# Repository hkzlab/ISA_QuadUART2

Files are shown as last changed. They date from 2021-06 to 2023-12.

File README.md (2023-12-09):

# ISA Quad UART Adapter (2 + 2)

## Introduction

This 8-bit ISA board will provide 4 serial RS232 ports using a single 16C554 controller.

Port 1 and 2 are exposed on the bracked as DB9 male connectors. Port 3 and 4 are internal.

IRQs will be shared between port 1/3 and port 2/4.

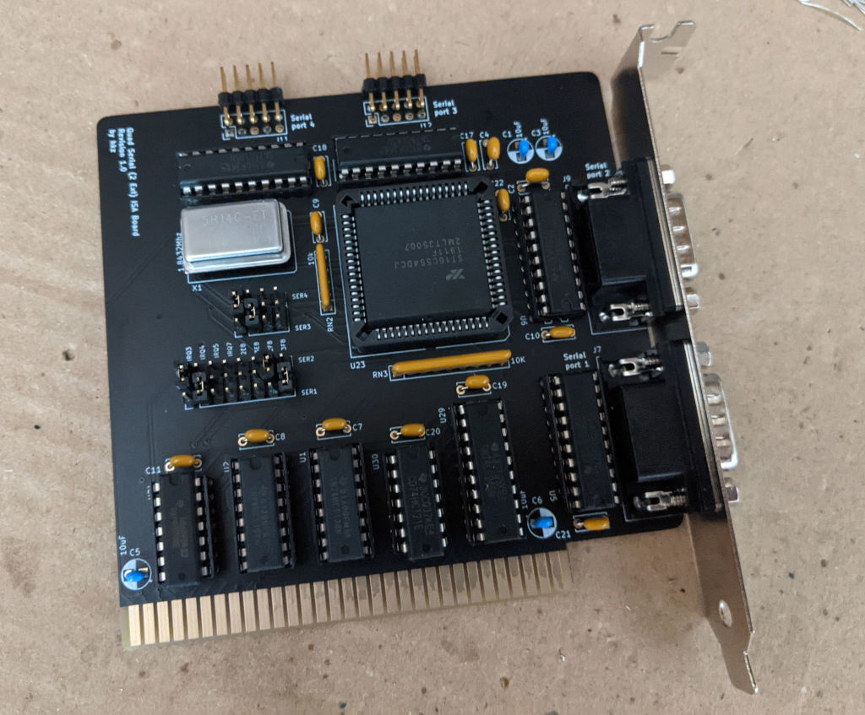
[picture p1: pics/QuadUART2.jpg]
ISA QuadUART 2


### Disclaimer

I take NO responsibility for what happens if you decide to build and use this card. Your computer might crash, catch fire or be destroyed in other nasty ways.
You're encourauged to take what you deem fit from this, and use it in your projects!

## Configuration

This board is configured via two blocks of jumpers:

```text
    .... SER4 
    ....
    .... SER3
IIII2323
RRRREEFF
QQQQ8888
3457
........ SER2
........
........ SER1
```

The upper block will select the address for port 3 (first row) and port 4 (third row). To select an address, you need to bridge the middle row at the specified address with the top or bottom row (depending on which port you wish to assign that address).

The bottom block selects the address for ports 1 and 2, and the IRQs for ports 1/3 and 2/4. The principle is the same.

Default configuration is as follow:
```text
    |... SER4 
    ||..
    .|.. SER3
IIII2323
RRRREEFF
QQQQ8888
3457
|.....|. SER2
||....||
.|.....| SER1
```

Which will assign 0x3F8 to port 1, 0x2F8 to port 2, 0x3E8 to port 3 and 0x2E8 to port 4.
Port 1/3 will get IRQ4 and port 2/4 will get IRQ3.

## Bill of Materials

- 4x 10uF / 25v capacitors
- 13x 100nF / 25v ceramic capacitors
- 1x 9-pin 10k bussed resistor network (RN3)
- 1x 5-pin 10k bussed resistor network (RN2)
- 1x 1.8432Mhz DIP14 or DIP8 oscillator
- 2x DB9 right angle, male, PCB mount connector
- 1x 1x20pin 2.54mm straight header strip (you will cut this as needed)
- 1x 2x20pin 2.54mm straight header strip (you will cut this as needed)
- 1x 2x20pin 2.54mm angled header strip (you will cut this as needed)
- 4x 75C185 RS232 drivers (U5, U6, U25, U26)
- 2x 74HCT138 (U1, U2)
- 1x 74HCT32 (U24)
- 1x 74HCT21 (U30)
- 1x 74HCT245 (U29) (with some controllers, like TL16C554, I noticed improved stability by using a 74LS245)
- 1x SC16C654, ST16C554 (U23) (all the 16C554 / 16C654 should be compatible, but to get TL16C554 working properly I had to replace U29) 
- Jumpers for board configuration
- Keystone 9200-15 bracket
- 1x PLCC68 THT socket
 
## Credits

- Thanks to [@A-Small-Mice](https://github.com/A-Small-Mice) for the printable bracket

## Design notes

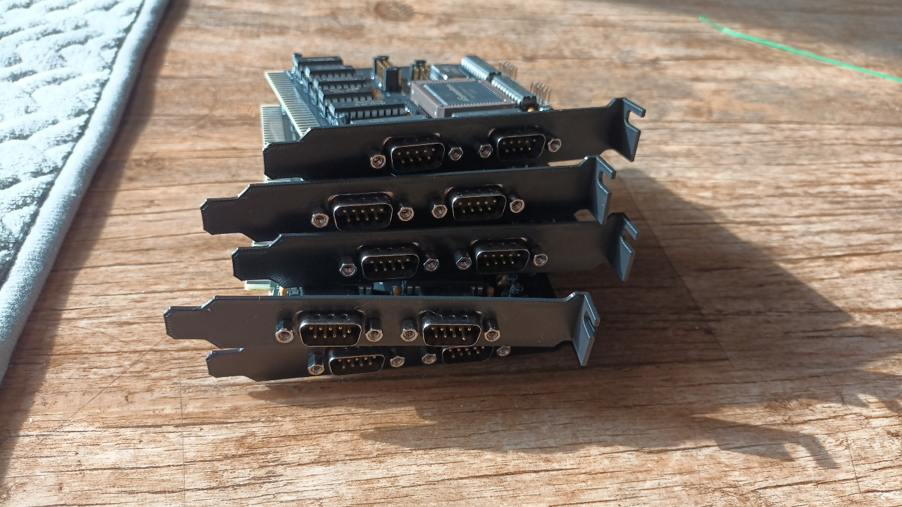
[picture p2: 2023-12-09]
3d_model/3dmodel.jpg

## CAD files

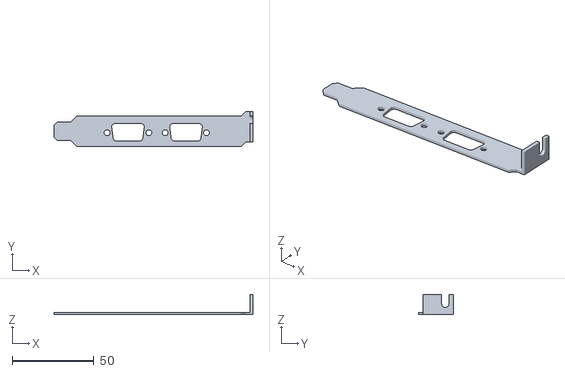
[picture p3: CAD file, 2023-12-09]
3d_model/ISA_QuadUART2_bracket.stl
121.7 x 21.4 x 12.4

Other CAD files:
3d_model/ISA_QuadUART2_bracket.f3d

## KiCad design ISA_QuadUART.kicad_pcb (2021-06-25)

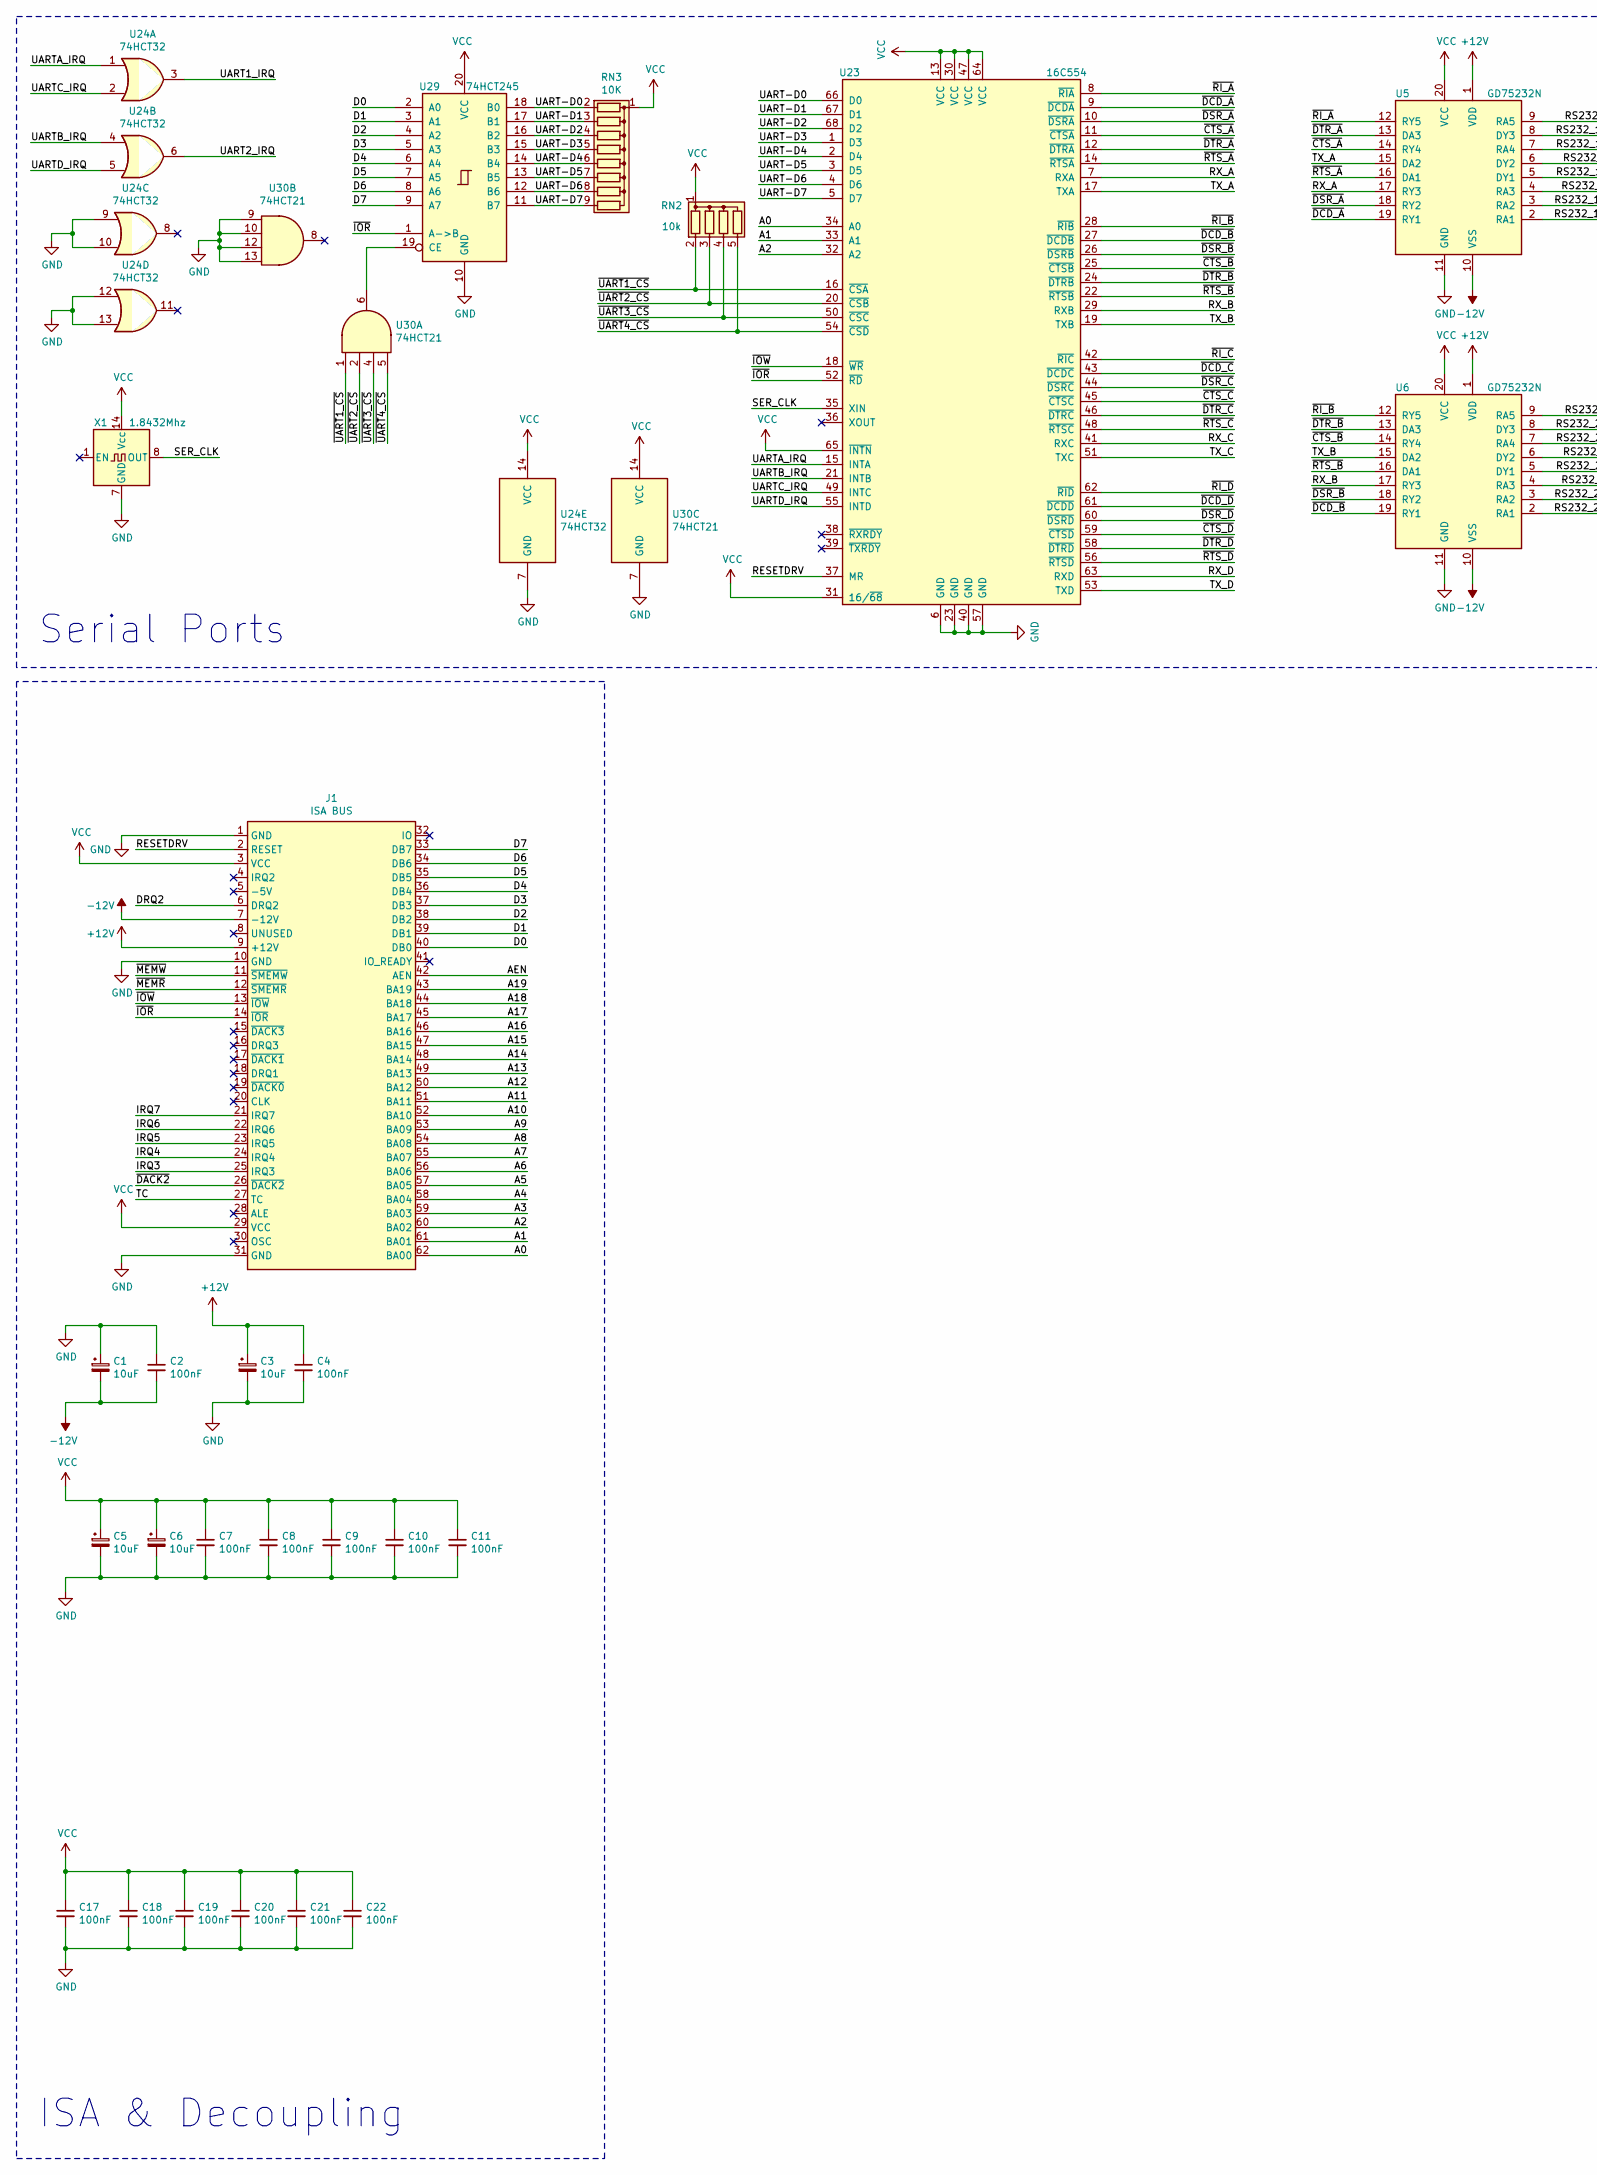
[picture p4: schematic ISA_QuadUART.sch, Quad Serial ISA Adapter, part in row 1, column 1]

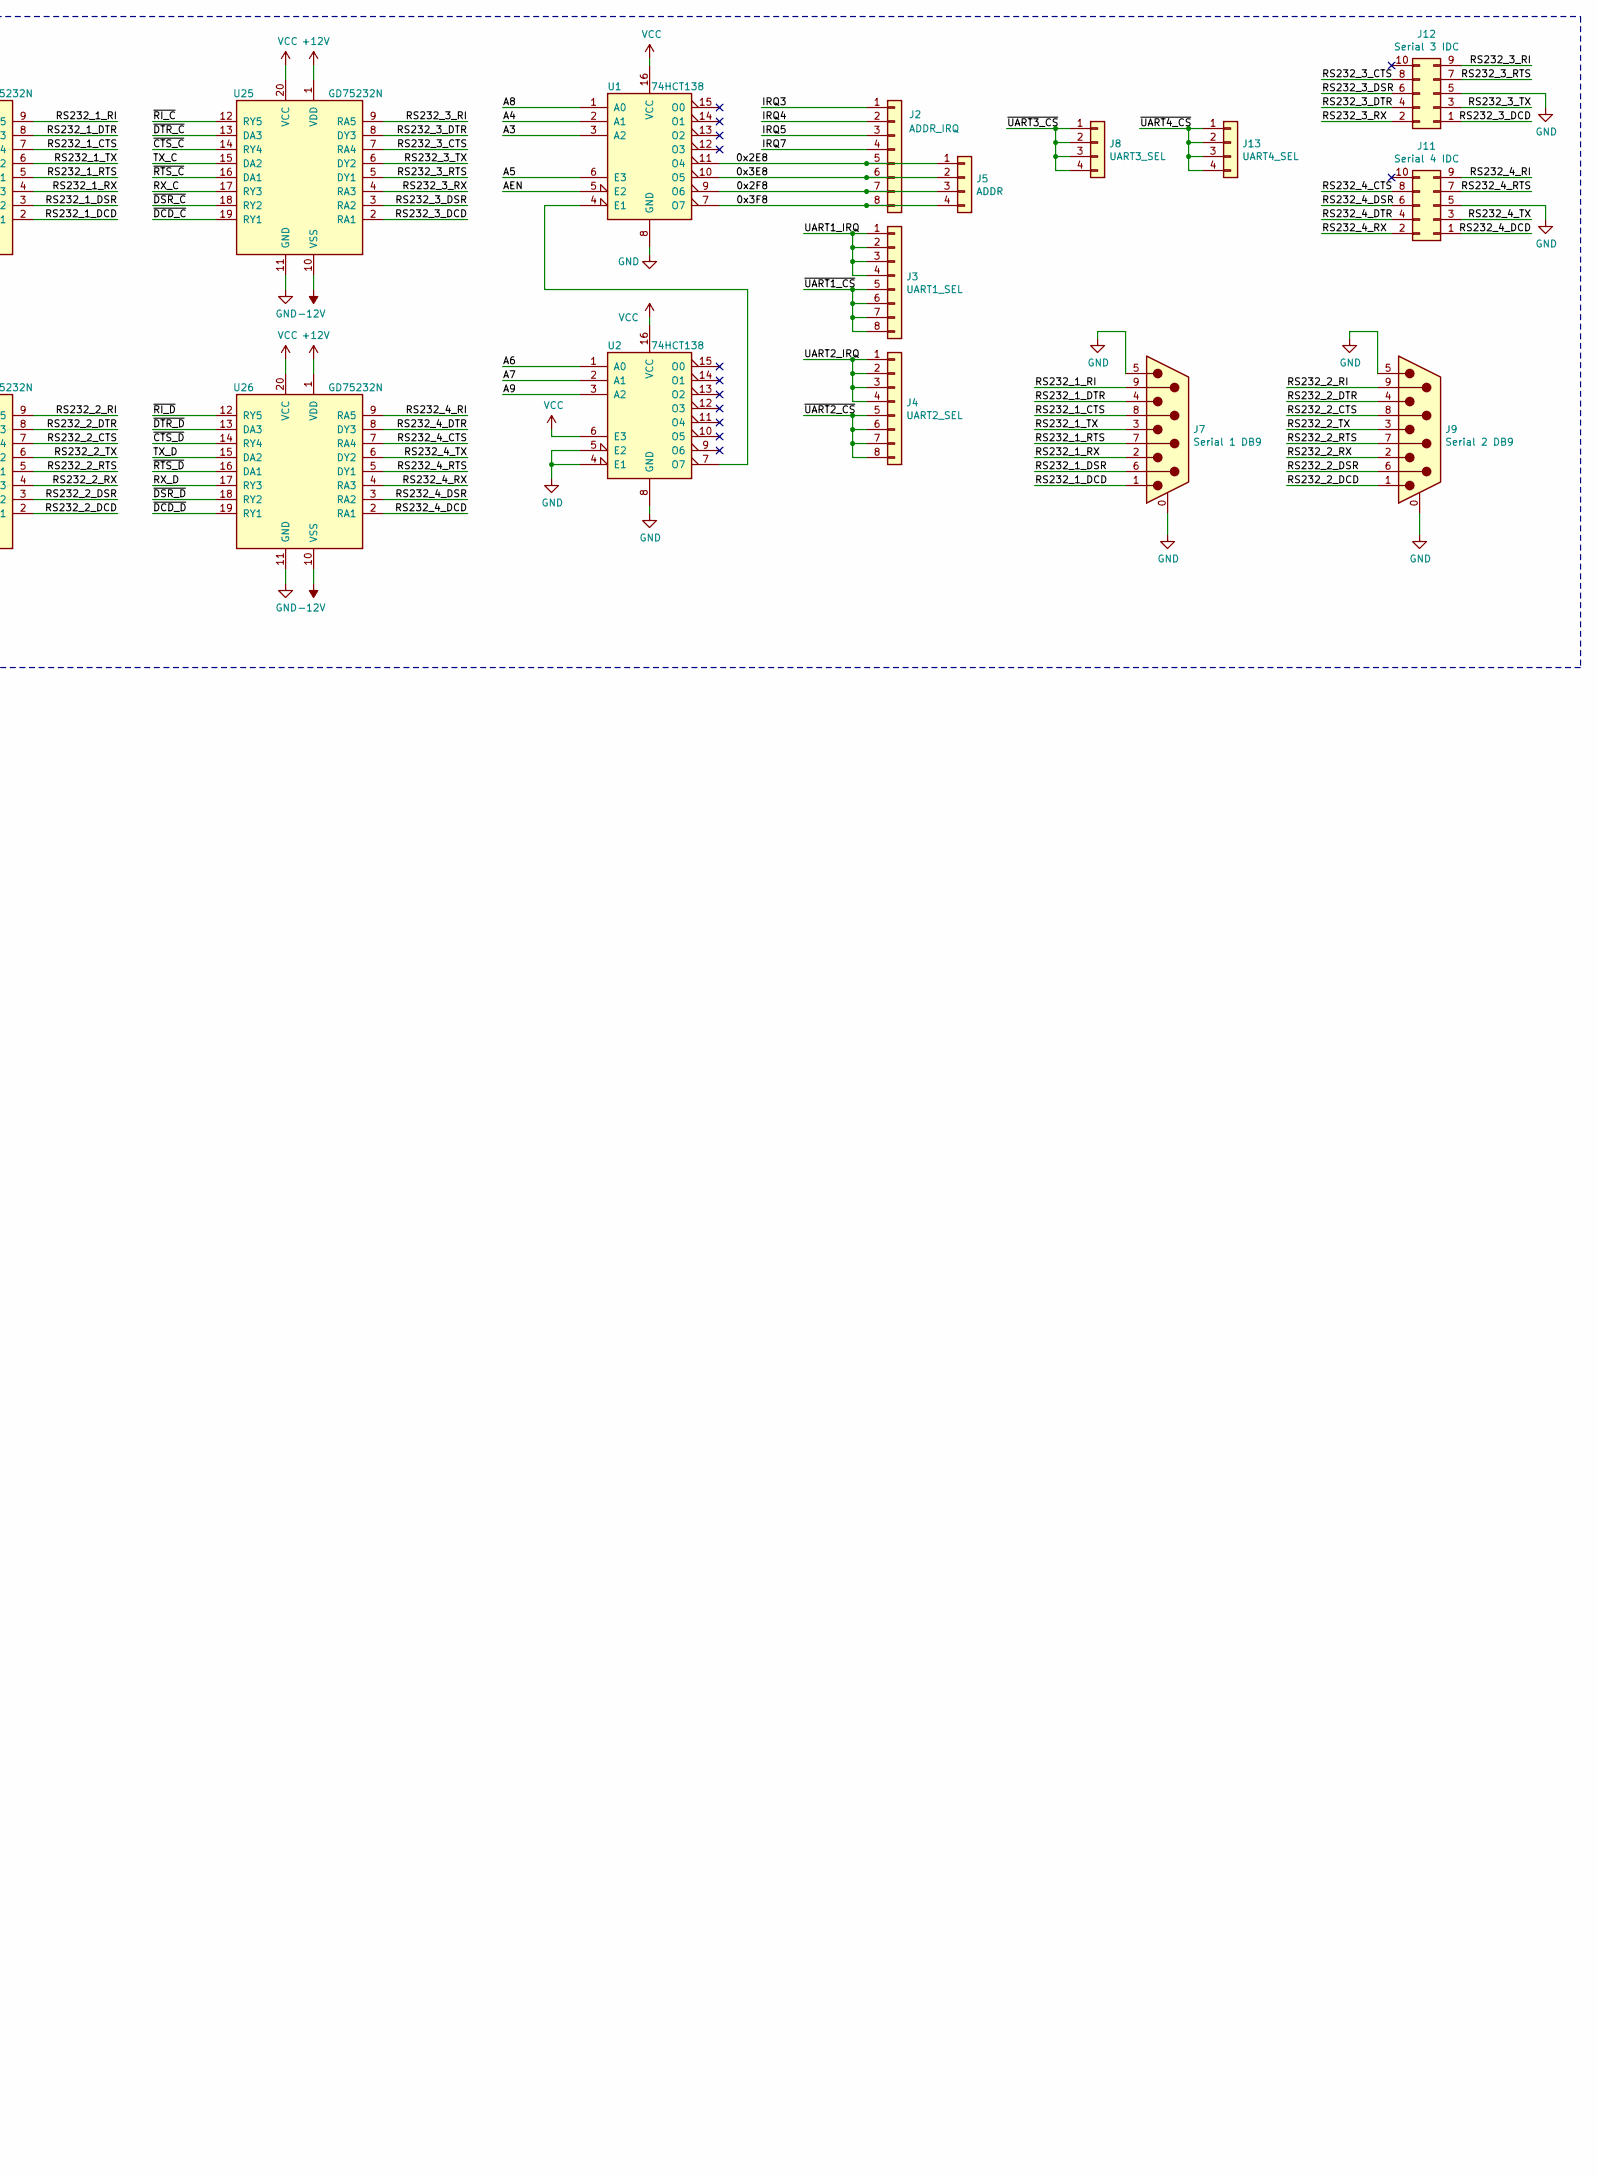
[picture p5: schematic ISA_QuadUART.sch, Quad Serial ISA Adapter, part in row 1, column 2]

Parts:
C1, C3, C5, C6: 10uF; CP_Radial_D5.0mm_P2.50mm
C2, C4, C7, C8, C9, C10, C11, C17, C18, C19, C20, C21, C22: 100nF; C_Disc_D6.0mm_W2.5mm_P5.00mm
J1: ISA BUS; Conn_Edge_PCB_ISA8
J2: ADDR_IRQ; PinHeader_1x08_P2.54mm_Vertical
J3: UART1_SEL; PinHeader_1x08_P2.54mm_Vertical
J4: UART2_SEL; PinHeader_1x08_P2.54mm_Vertical
J5: ADDR; PinHeader_1x04_P2.54mm_Vertical
J7: Serial 1 DB9; DSUB-9_Male_Horizontal_P2.77x2.84mm_EdgePinOffset7.70mm_Hou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
J8: UART3_SEL; PinHeader_1x04_P2.54mm_Vertical
J9: Serial 2 DB9; DSUB-9_Male_Horizontal_P2.77x2.84mm_EdgePinOffset7.70mm_Hou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
J11: Serial 4 IDC; PinHeader_2x05_P2.54mm_Vertical
J12: Serial 3 IDC; PinHeader_2x05_P2.54mm_Vertical
J13: UART4_SEL; PinHeader_1x04_P2.54mm_Vertical
RN2: 10k; R_Array_SIP5
RN3: 10K; R_Array_SIP9
U1, U2: 74HCT138; DIP-16_W7.62mm_LongPads
U5, U6, U25, U26: GD75232N; DIP-20_W7.62mm_LongPads
U23: 16C554; PLCC-68_THT-Socket
U24: 74HCT32; DIP-14_W7.62mm_LongPads
U29: 74HCT245; DIP-20_W7.62mm_LongPads
U30: 74HCT21; DIP-14_W7.62mm_LongPads
X1: 1.8432Mhz; Oscillator_DIP-14-8

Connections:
+12V: C3.1, C4.1, J1.9 (+12V), U5.1 (VDD), U6.1 (VDD), U25.1 (VDD), U26.1 (VDD)
-12V: C1.2, C2.2, J1.7 (-12V), U5.10 (VSS), U6.10 (VSS), U25.10 (VSS), U26.10 (VSS)
/0x2E8: J2.5, J5.1, U1.11 (O4)
/0x2F8: J2.7, J5.3, U1.9 (O6)
/0x3E8: J2.6, J5.2, U1.10 (O5)
/0x3F8: J2.8, J5.4, U1.7 (O7)
/A0: J1.62 (BA00), U23.34 (A0)
/A1: J1.61 (BA01), U23.33 (A1)
/A2: J1.60 (BA02), U23.32 (A2)
/A3: J1.59 (BA03), U1.3 (A2)
/A4: J1.58 (BA04), U1.2 (A1)
/A5: J1.57 (BA05), U1.6 (E3)
/A6: J1.56 (BA06), U2.1 (A0)
/A7: J1.55 (BA07), U2.2 (A1)
/A8: J1.54 (BA08), U1.1 (A0)
/A9: J1.53 (BA09), U2.3 (A2)
/A10: J1.52 (BA10)
/A11: J1.51 (BA11)
/A12: J1.50 (BA12)
/A13: J1.49 (BA13)
/A14: J1.48 (BA14)
/A15: J1.47 (BA15)
/A16: J1.46 (BA16)
/A17: J1.45 (BA17)
/A18: J1.44 (BA18)
/A19: J1.43 (BA19)
/AEN: J1.42 (AEN), U1.5 (E2)
/D0: J1.40 (DB0), U29.2 (A0)
/D1: J1.39 (DB1), U29.3 (A1)
/D2: J1.38 (DB2), U29.4 (A2)
/D3: J1.37 (DB3), U29.5 (A3)
/D4: J1.36 (DB4), U29.6 (A4)
/D5: J1.35 (DB5), U29.7 (A5)
/D6: J1.34 (DB6), U29.8 (A6)
/D7: J1.33 (DB7), U29.9 (A7)
/DRQ2: J1.6 (DRQ2)
/IRQ3: J1.25 (IRQ3), J2.1
/IRQ4: J1.24 (IRQ4), J2.2
/IRQ5: J1.23 (IRQ5), J2.3
/IRQ6: J1.22 (IRQ6)
/IRQ7: J1.21 (IRQ7), J2.4
/RESETDRV: J1.2 (RESET), U23.37 (MR)
/RS232_1_CTS: J7.8, U5.7 (RA4)
/RS232_1_DCD: J7.1, U5.2 (RA1)
/RS232_1_DSR: J7.6, U5.3 (RA2)
/RS232_1_DTR: J7.4, U5.8 (DY3)
/RS232_1_RI: J7.9, U5.9 (RA5)
/RS232_1_RTS: J7.7, U5.5 (DY1)
/RS232_1_RX: J7.2, U5.4 (RA3)
/RS232_1_TX: J7.3, U5.6 (DY2)
/RS232_2_CTS: J9.8, U6.7 (RA4)
/RS232_2_DCD: J9.1, U6.2 (RA1)
/RS232_2_DSR: J9.6, U6.3 (RA2)
/RS232_2_DTR: J9.4, U6.8 (DY3)
/RS232_2_RI: J9.9, U6.9 (RA5)
/RS232_2_RTS: J9.7, U6.5 (DY1)
/RS232_2_RX: J9.2, U6.4 (RA3)
/RS232_2_TX: J9.3, U6.6 (DY2)
/RS232_3_CTS: J12.8, U25.7 (RA4)
/RS232_3_DCD: J12.1, U25.2 (RA1)
/RS232_3_DSR: J12.6, U25.3 (RA2)
/RS232_3_DTR: J12.4, U25.8 (DY3)
/RS232_3_RI: J12.9, U25.9 (RA5)
/RS232_3_RTS: J12.7, U25.5 (DY1)
/RS232_3_RX: J12.2, U25.4 (RA3)
/RS232_3_TX: J12.3, U25.6 (DY2)
/RS232_4_CTS: J11.8, U26.7 (RA4)
/RS232_4_DCD: J11.1, U26.2 (RA1)
/RS232_4_DSR: J11.6, U26.3 (RA2)
/RS232_4_DTR: J11.4, U26.8 (DY3)
/RS232_4_RI: J11.9, U26.9 (RA5)
/RS232_4_RTS: J11.7, U26.5 (DY1)
/RS232_4_RX: J11.2, U26.4 (RA3)
/RS232_4_TX: J11.3, U26.6 (DY2)
/RX_A: U5.17 (RY3), U23.7 (RXA)
/RX_B: U6.17 (RY3), U23.29 (RXB)
/RX_C: U23.41 (RXC), U25.17 (RY3)
/RX_D: U23.63 (RXD), U26.17 (RY3)
/SER_CLK: U23.35 (XIN), X1.8 (OUT)
/TC: J1.27 (TC)
/TX_A: U5.15 (DA2), U23.17 (TXA)
/TX_B: U6.15 (DA2), U23.19 (TXB)
/TX_C: U23.51 (TXC), U25.15 (DA2)
/TX_D: U23.53 (TXD), U26.15 (DA2)
/UART1_IRQ: J3.1, J3.2, J3.3, J3.4, U24.3
/UART2_IRQ: J4.1, J4.2, J4.3, J4.4, U24.6
/UART-D0: RN3.2 (R1), U23.66 (D0), U29.18 (B0)
/UART-D1: RN3.3 (R2), U23.67 (D1), U29.17 (B1)
/UART-D2: RN3.4 (R3), U23.68 (D2), U29.16 (B2)
/UART-D3: RN3.5 (R4), U23.1 (D3), U29.15 (B3)
/UART-D4: RN3.6 (R5), U23.2 (D4), U29.14 (B4)
/UART-D5: RN3.7 (R6), U23.3 (D5), U29.13 (B5)
/UART-D6: RN3.8 (R7), U23.4 (D6), U29.12 (B6)
/UART-D7: RN3.9 (R8), U23.5 (D7), U29.11 (B7)
/UARTA_IRQ: U23.15 (INTA), U24.1
/UARTB_IRQ: U23.21 (INTB), U24.4
/UARTC_IRQ: U23.49 (INTC), U24.2
/UARTD_IRQ: U23.55 (INTD), U24.5
/~CTS_A: U5.14 (RY4), U23.11 (~CTSA)
/~CTS_B: U6.14 (RY4), U23.25 (~CTSB)
/~CTS_C: U23.45 (~CTSC), U25.14 (RY4)
/~CTS_D: U23.59 (~CTSD), U26.14 (RY4)
/~DACK2: J1.26 (~DACK2)
/~DCD_A: U5.19 (RY1), U23.9 (~DCDA)
/~DCD_B: U6.19 (RY1), U23.27 (~DCDB)
/~DCD_C: U23.43 (~DCDC), U25.19 (RY1)
/~DCD_D: U23.61 (~DCDD), U26.19 (RY1)
/~DSR_A: U5.18 (RY2), U23.10 (~DSRA)
/~DSR_B: U6.18 (RY2), U23.26 (~DSRB)
/~DSR_C: U23.44 (~DSRC), U25.18 (RY2)
/~DSR_D: U23.60 (~DSRD), U26.18 (RY2)
/~DTR_A: U5.13 (DA3), U23.12 (~DTRA)
/~DTR_B: U6.13 (DA3), U23.24 (~DTRB)
/~DTR_C: U23.46 (~DTRC), U25.13 (DA3)
/~DTR_D: U23.58 (~DTRD), U26.13 (DA3)
/~IOR: J1.14 (~IOR), U23.52 (~RD~), U29.1 (A->B)
/~IOW: J1.13 (~IOW), U23.18 (~WR~)
/~MEMR: J1.12 (~SMEMR)
/~MEMW: J1.11 (~SMEMW)
/~RI_A: U5.12 (RY5), U23.8 (~RIA)
/~RI_B: U6.12 (RY5), U23.28 (~RIB)
/~RI_C: U23.42 (~RIC), U25.12 (RY5)
/~RI_D: U23.62 (~RID), U26.12 (RY5)
/~RTS_A: U5.16 (DA1), U23.14 (~RTSA)
/~RTS_B: U6.16 (DA1), U23.22 (~RTSB)
/~RTS_C: U23.48 (~RTSC), U25.16 (DA1)
/~RTS_D: U23.56 (~RTSD), U26.16 (DA1)
/~UART1_CS: J3.5, J3.6, J3.7, J3.8, RN2.2 (R1), U23.16 (~CSA), U30.1
/~UART2_CS: J4.5, J4.6, J4.7, J4.8, RN2.3 (R2), U23.20 (~CSB), U30.2
/~UART3_CS: J8.1, J8.2, J8.3, J8.4, RN2.4 (R3), U23.50 (~CSC), U30.4
/~UART4_CS: J13.1, J13.2, J13.3, J13.4, RN2.5 (R4), U23.54 (~CSD), U30.5
GND: C1.1, C2.1, C3.2, C4.2, C5.2, C6.2, C7.2, C8.2, C9.2, C10.2, C11.2, C17.2, C18.2, C19.2, C20.2, C21.2, C22.2, J1.1 (GND), J1.10 (GND), J1.31 (GND), J7.0 (PAD), J7.5, J9.0 (PAD), J9.5, J11.5, J12.5, U1.8 (GND), U2.4 (E1), U2.5 (E2), U2.8 (GND), U5.11 (GND), U6.11 (GND), U23.6 (GND), U23.23 (GND), U23.40 (GND), U23.57 (GND), U24.7 (GND), U24.9, U24.10, U24.12, U24.13, U25.11 (GND), U26.11 (GND), U29.10 (GND), U30.7 (GND), U30.9, U30.10, U30.12, U30.13, X1.7 (GND)
unnamed: U1.4 (E1), U2.7 (O7)
unnamed: U29.19 (CE), U30.6
VCC: C5.1, C6.1, C7.1, C8.1, C9.1, C10.1, C11.1, C17.1, C18.1, C19.1, C20.1, C21.1, C22.1, J1.3 (VCC), J1.29 (VCC), RN2.1 (common), RN3.1 (common), U1.16 (VCC), U2.6 (E3), U2.16 (VCC), U5.20 (VCC), U6.20 (VCC), U23.13 (VCC), U23.30 (VCC), U23.31 (16/~68), U23.47 (VCC), U23.64 (VCC), U23.65 (~INTN), U24.14 (VCC), U25.20 (VCC), U26.20 (VCC), U29.20 (VCC), U30.14 (VCC), X1.14 (Vcc)

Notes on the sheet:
Serial Ports
ISA & Decoupling

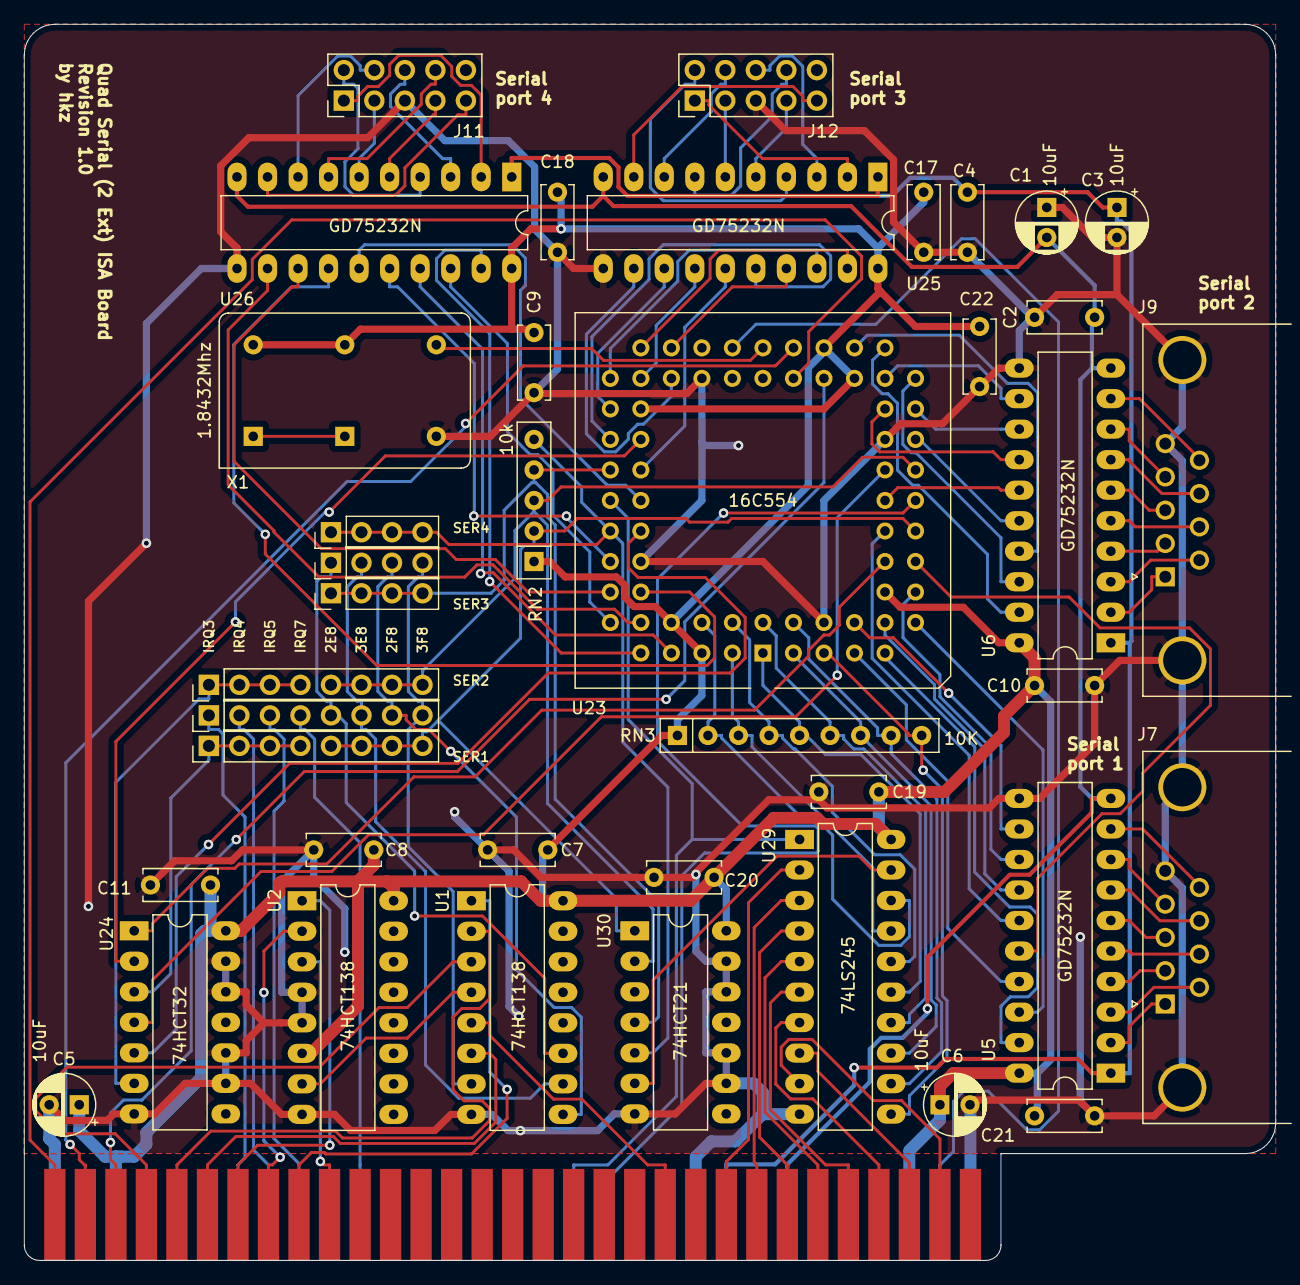
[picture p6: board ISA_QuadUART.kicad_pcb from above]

Board: 2 copper layers, 104.1 x 102.9 mm, 41 parts (0 on the bottom side), 119 nets.

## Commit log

2021-02-20 Import older project
    [ISA_SerPaROM.kicad_pcb, ISA_SerPaROM.sch]
2021-02-20 Additional parallel ports
    [ISA_SerPaROM.sch]
2021-02-20 Route Serial/Parallel/ROM board
    [ISA_SerPaROM.kicad_pcb, ISA_SerPaROM.sch]
2021-02-20 Fix silkscreen
    [ISA_SerPaROM.kicad_pcb]
2021-02-20 Add rev 1.0 gerbers
2021-02-20 Save gerber path
    [ISA_SerPaROM.kicad_pcb]
2021-02-22 Add notes to the schematic, cleaned the silkscreen
    [ISA_SerPaROM.kicad_pcb, ISA_SerPaROM.sch]
2021-02-23 Update mask and gerbers
    [ISA_SerPaROM.kicad_pcb]
2021-03-17 Update silkscreen
    [ISA_SerPaROM.kicad_pcb, ISA_SerPaROM.sch]
2021-03-18 set resistor type for '554 pullup to 4.7k
    [ISA_SerPaROM.kicad_pcb]
2021-03-18 Added LED bar and moved serial leds
    [ISA_SerPaROM.kicad_pcb, ISA_SerPaROM.sch]
2021-03-18 Mark pin 36 as unconnected
    [ISA_SerPaROM.sch]
2021-03-19 Mark some active low signals as such in parport
    [ISA_SerPaROM.sch]
2021-03-19 Remove ROM, add buffer for uart
    [ISA_SerPaROM.kicad_pcb, ISA_SerPaROM.sch]
2021-03-19 Add new gerber, use 74HCT21
    [ISA_SerPaROM.kicad_pcb, ISA_SerPaROM.sch]
2021-03-19 Slightly adjust the silkscreen
    [ISA_SerPaROM.kicad_pcb]
2021-03-19 Updated silkscreen, again
    [ISA_SerPaROM.kicad_pcb]
2021-03-20 Adjust silkscreen
    [ISA_SerPaROM.kicad_pcb]
2021-03-21 Add first revision of single quad uart
    [ISA_QuadUART.kicad_pcb, ISA_QuadUART.sch, ISA_SerPaROM.kicad_pcb]
2021-03-21 rerouted pcb
    [ISA_QuadUART.kicad_pcb]
2021-04-16 Add bracket in BOM
2021-04-16 Add component in BOM
2021-04-16 Add PLCC socket
2021-04-27 Add 2 external serial ports
    [ISA_QuadUART.kicad_pcb, ISA_QuadUART.sch]
2021-04-27 Removed gerbers from old board
2021-04-27 Move connectors
    [ISA_QuadUART.kicad_pcb]
2021-04-27 Change ground plane on board
    [ISA_QuadUART.kicad_pcb]
2021-04-28 Slight fixes to silkscreen
    [ISA_QuadUART.kicad_pcb]
2021-04-28 Slightly better filling for ground plane
    [ISA_QuadUART.kicad_pcb]
2021-04-28 Create gerbers
2021-05-25 Add footprint for keystone 9200-15
    [ISA_QuadUART.kicad_pcb]
2021-06-20 Redone some power traces
    [ISA_QuadUART.kicad_pcb]
2021-06-25 Update gerbers
    [ISA_QuadUART.kicad_pcb]
2021-11-09 Update Kicad url
2023-12-09 Add a 3D model for ISA_QuadUART2
    [ISA_QuadUART2_bracket.f3d, ISA_QuadUART2_bracket.stl]
2023-12-09 Add credits for the bracket
